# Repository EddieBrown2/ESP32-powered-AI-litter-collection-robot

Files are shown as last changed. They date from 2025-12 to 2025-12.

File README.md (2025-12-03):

# ESP32 powered AI litter collection robot
One of the biggest problems in the world today is pollution which includes litter outside and in buildings. To help solve this problem, I am going to create a small autonomous robot capable of detecting and moving litter. This robot will be capable of removing plastic environment, in order to protect them.
I have attached an entire breakdown of the project's progress if the pdf file with the name "ESP32-powered-AI-litter-collection-robot"
Youtube account with videos of progress : https://www.youtube.com/@EddieBrown-j3n

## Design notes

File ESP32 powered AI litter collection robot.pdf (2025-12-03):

ESP32 powered AI litter collection robot

Table of Contents

## Preparation

## Project overview

One of the biggest problems in the world today is pollution which includes litter outside and in buildings. To help solve this problem, I am going to create a small autonomous robot capable of detecting and moving litter. This robot will be capable of removing plastic from internal and external environments to prevent damage to the infrastructure and ecosystems of these spaces. To achieve this, I will need to follow the following specifications:
- No 3d printed components can be larger than 220 x 220 x 270 mm as these are the dimensions of the print volume for the 3d printer I will be using. I will use a 3d printer as it is quick and allows for precise, replicable manufacturing of the components in my design.
- The cost of all the components should be around £50 but no more than £100. This will ensure the robot is cheap to manufacture and can be easily replicated.
- The robot will need to include a camera for image recognition which decreases the options for microcontrollers that can be used.
- The microcontroller used also needs plenty of free GPIO pins to connect the various components necessary for the design.

## Components

For this project, I have chosen to source all the electrical components from the website Pi hut rather than directly buying from a direct electronics component’s seller such as Digi key. This reduces the number of options I have for components to use for the project but will allow me to receive the components quicker and with easier to access documentation.

Microcontroller
I will use an esp32 microcontroller to create this project, rather than a single board computer such as a raspberry pi. This will result in a lower processing power but the positive of a smaller form factor to fit into the chassis and lower power and cooling requirements. However, this also means I will only be able to power the components with 3.3V rather than 5V due to the limited power output of esp32 boards. This will limit my options in terms of components, most notably motors, but should still allow for a successful design.
The specific board I have chosen to use is the Xiao esp32 s3 sense. This is due to its small form factor, as well as having a built-in camera which leaves all the GPIO pins free to wire components to, making it ideal for my project. As well as this, it has an inbuilt module and attachment to be powered by a 3.7v lithium polymer battery and recharge the battery. This makes It easier for my project as the battery

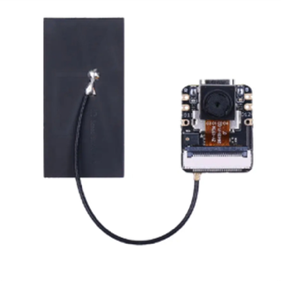
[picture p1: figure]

doesn’t have to be swapped out as often. Battery
I have chosen to use a 3.7v LIPO battery with 1200mAh of capacity. This battery will connect directly to the board, which reduces the need for extra components. It also maintains a small for factor coming in at only 5.3 x 35.5 x 64.5 mm making it ideal for a small form factor chassis.

Distance sensor
Due to the limited voltage output of the esp32 s3 chip I am using, I cannot use a standard 5v HC-SR04 ultrasonic distance sensor without the use of a voltage converter. Since using a converter can lead to unreliability in the operation of the sensor, I will instead use an ultrasonic distance sensor that uses a RCWL-1601 board instead. This means that it can be powered with voltages between 3 – 5V, making it compatible with my board.
Motors
For the powering of the wheels, I will use 2 TT Motors (which can be powered by 3 – 6V), one for each wheel. Unfortunately, as the battery only outputs 3.7V, and servo motors require an input of 5V, I will use a third TT motor to drive the claw mechanism. This means I will need to use a claw mechanism that can be continuously driven, rather than a pivot-based design.

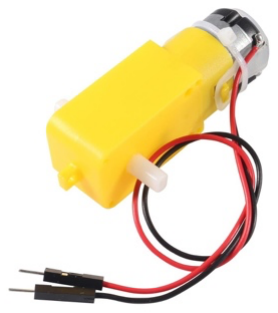
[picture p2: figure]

To drive these motors, I will use 2 HR8833 DFROBOT motor drivers one of which will allow me to power both the wheel motors and the other for just the claw driving motor. This motor driver is much smaller than most which will help limit the weight and size of my project.

Other Components
Other components I will use are:
- Proto board to allow me to easily solder the parts together without the need to design an order a custom PCB.
- Ceramic and electrolytic capacitors to
smoothen the signal between the battery and the
motor driver as well as between the motor driver and

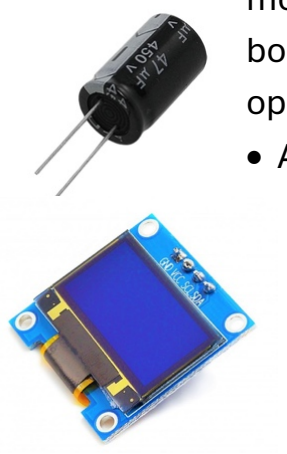
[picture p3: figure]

board. This will result in more reliable and consistent operation of the components.
- A simple OLED display to show information relating to the operation of the robot.
- Simple push buttons to allowing changing settings of various parts of the system when a WIFI – connection is not available.

## Full components List

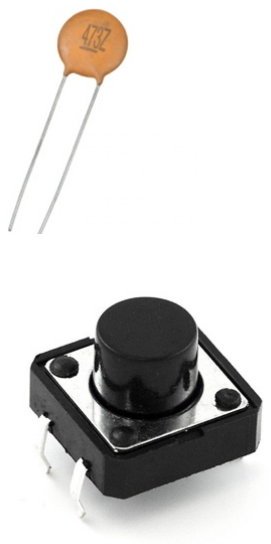
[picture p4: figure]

Component | Price
Xiao ESP32 S3 Sense | £13.50
3.7V 1200mAh LIPO battery + JST connector | £8.70
RCWL-1601 ultrasonic distance sensor | £3.90
3V TT motor * 3 | £7.80
HR8833 Motor Driver * 2 | £8.80
Proto board | £4.40
Ceramic and Electrolytic capacitors | £3.80
OLED display | £4.00
Push buttons | £2.20
Total Price | £57.10

Using these components the total price is £57.10 which makes it below the budget of £100 due to the use of the ahordable ESP32 motors as well as the use of TT motors rather than servos.

## CAD design

I have chosen to use Fusion 360 to design the 3d printed components for this project as it is a software I am familiar with and allows for the parts to be easily exported to be 3d printed.

## Claw Mechanism

I chose to first design the claw mechanism as this will heavily influence the size and shape of the final body design to house the motors, circuitry and other components.

Claw Design Ideas
I started by experimenting with various claw designs to determine the most optimal design bearing in mind the following factors:
- It must be driven by continuous rotation as that is the form of motion delivered by the TT motor I will be using.
- Have a small total size to avoid the size of the robot becoming too large. In attempt to achieve this, I will try to minimise the number of components involved in the design.

Design 1
Initially, I tried experimenting with a dual pivot driven claw, like the one showed below. However, this required a lot of components to keep the desired form factor. Furthermore, the complex geometry made it dihicult to simulate, and it would likely get jammed if 3d printed due to the large number of moving parts

Design 2
Due to the dihiculty of designs that only use rotary motion, I decided to use a slider-based design instead. To achieve this, I created a mechanism only drives one slider along the y-axis. This slider then connects to a slider for each claw along the x-axis. This results in a grabbing motion shown in the diagram below as well as the video. This design uses significantly less components while maintaining a small form factor which makes it ideal for my design. However, the rotary motion driving the claw means it is only in a tight grip for a small portion of the rotation.

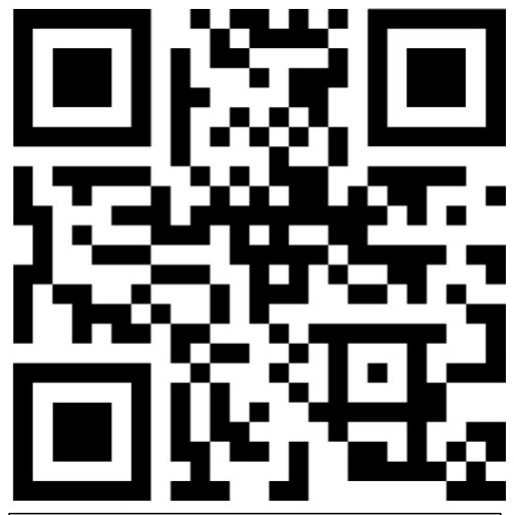
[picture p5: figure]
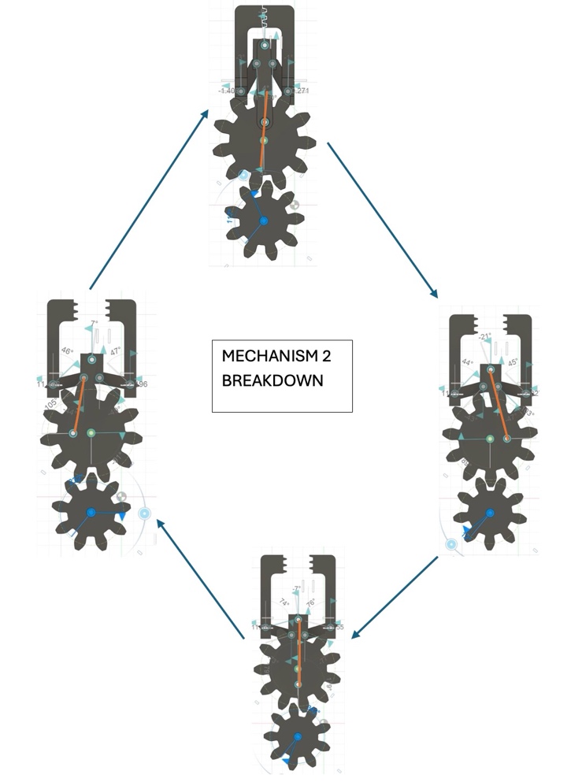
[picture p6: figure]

Video Of Mechanism

Chosen claw design
For my design I will use the second design as it is significantly more ehicient than the first.
Next, I will design the body which will be heavily influenced by the size and form factor of the chosen claw design.

## Body design

For the body design to be successful, I will need to follow the following specifications:
- It can be no larger than 220 x 220 x 270 mm as otherwise it won’t fit in the print space, I have available.
- It will need space to store the 3 TT motors which are 22.6 * 22.3 * 69.4 mm but the size of the space for each motor will have to be a millimetre or two larger to allow for tolerance when 3d printing.
- I will need to leave an open space that can hold the 50 * 70 mm perf board which the components will be soldered to.

Body design prototyping

Design 1
Initially, I tried to create a design where the motor holders were rotated along the X-axis to minimise the size of the chassis. However, this resulted in the design having a large vertical size, which would increase the cameras distance away from the claw and would also result in the design being di>icult to 3d print due to creating an excessive number of overhangs requiring lots of filament being needed to support the overhangs.

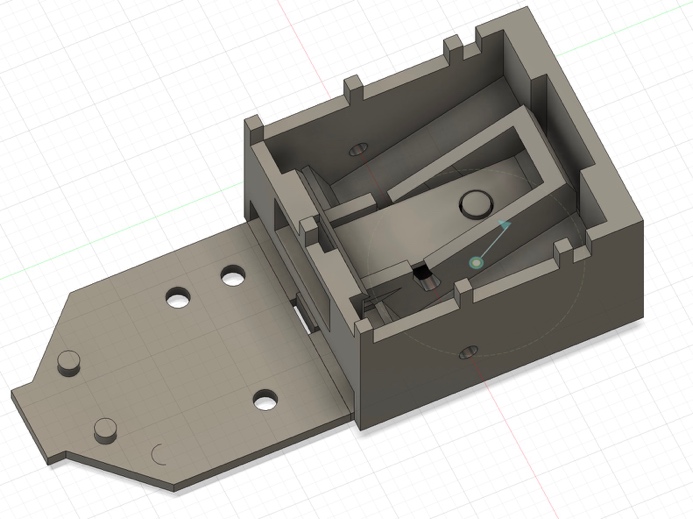
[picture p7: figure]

Design 2
I then tried a design which the motors were held flat and the camera could be held in front of the mechanism. However, this design didn’t allow space to store the circuitry.

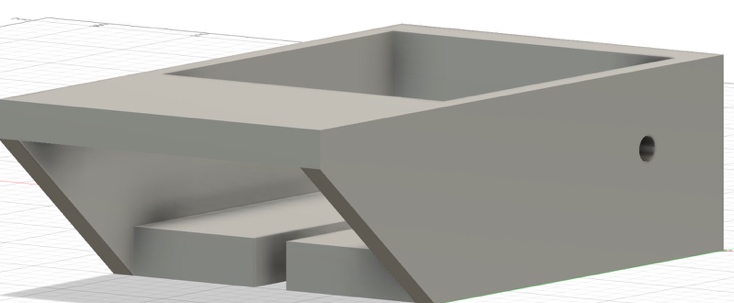
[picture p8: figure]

Design 3
For the third and final implementation of the design I split the design into the main body and a separate part to hold the circuitry and ultrasonic distance sensor. I also implemented railings into this design and adjusted the mechanism to fit.

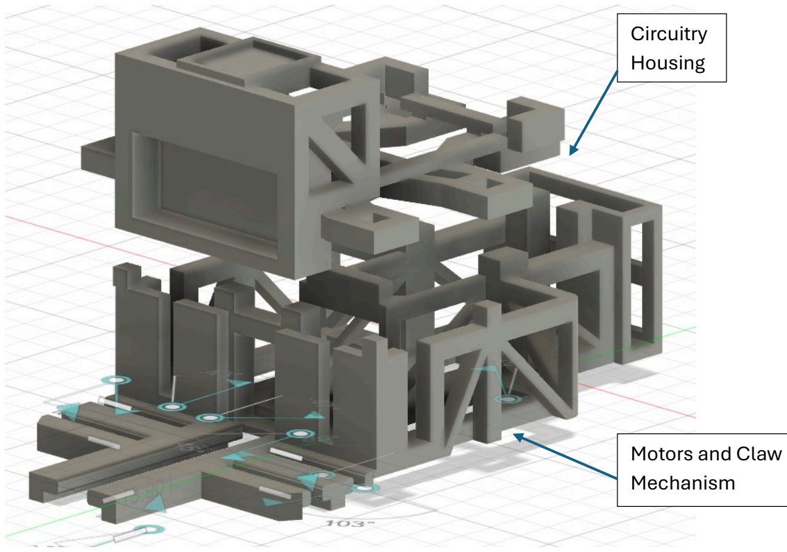
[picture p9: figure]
Circuitry Housing; Motors and Claw Mechanism
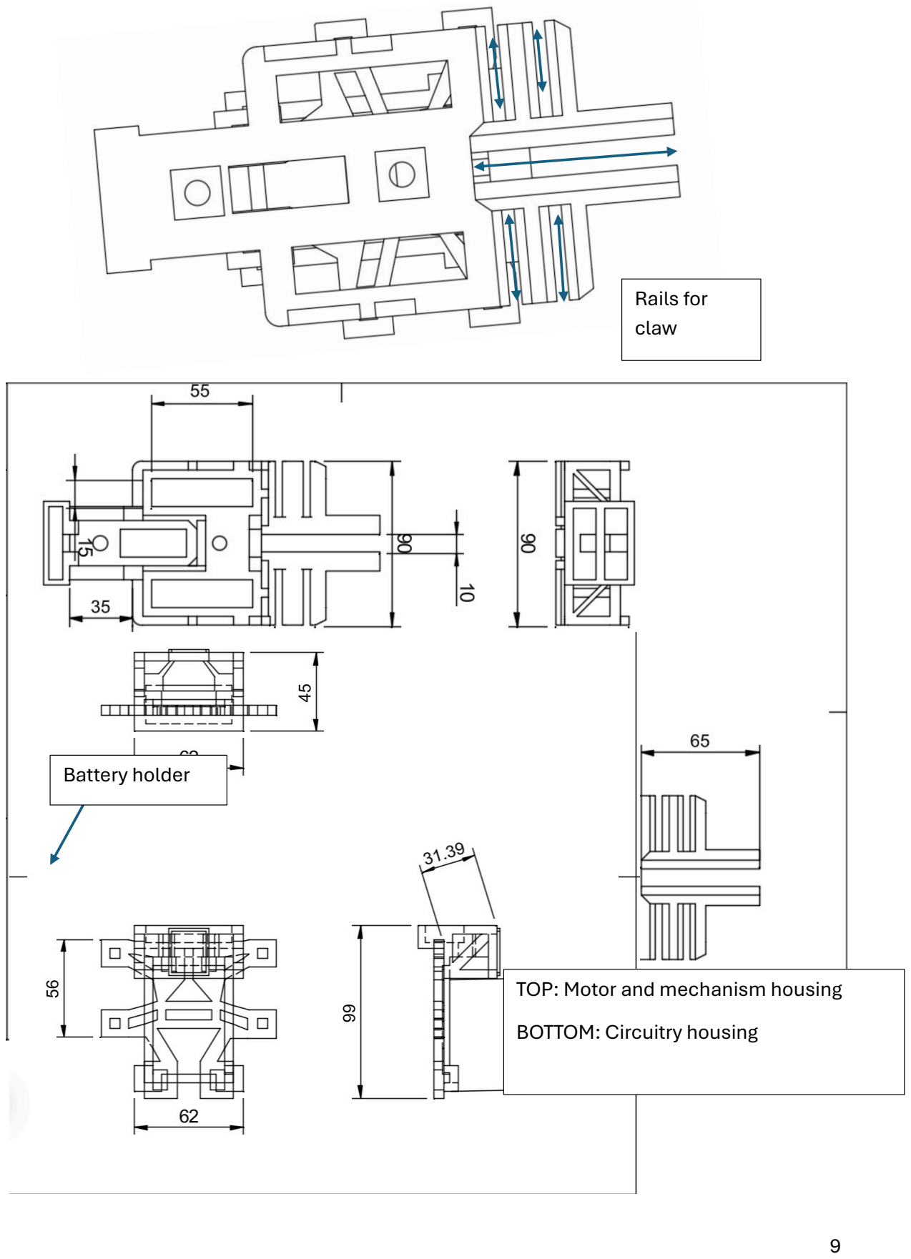
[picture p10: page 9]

Rails for
claw

TOP: Motor and mechanism housing BOTTOM: Circuitry housing

Battery holder

## Wheel Design

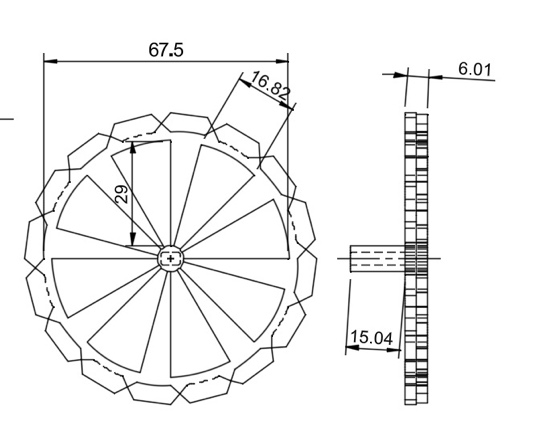
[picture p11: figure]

I chose to use a wheel with a ridged circumference in order to increase the friction and so also increase the robots grip and ability to manoeuvre across trickier terrains such as carpet or grass

## Full assembly

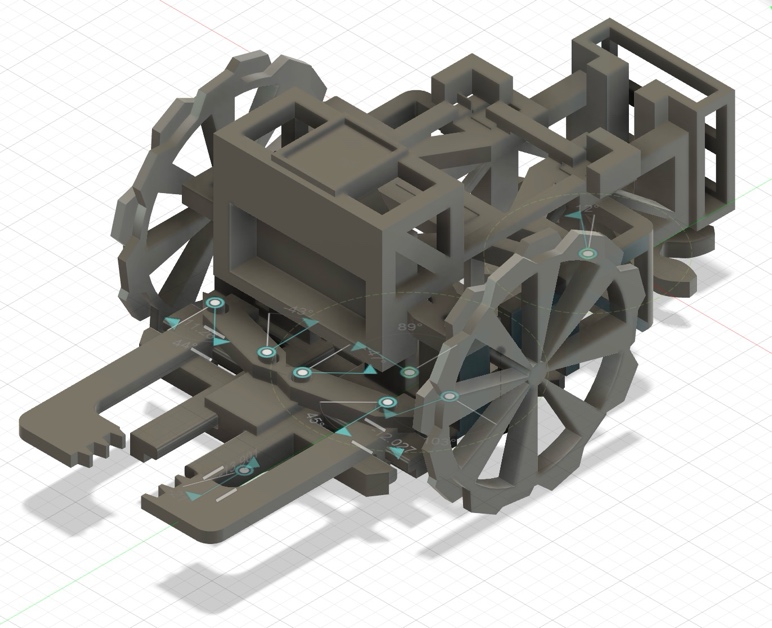
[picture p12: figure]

The picture to the left displays the entire assembly of the finished design. The total size is 110 x 70 x 200mm which means it can all be easily printed in the available print space using a minimal amount of filament

More points of contact than normal wheel = increased grip

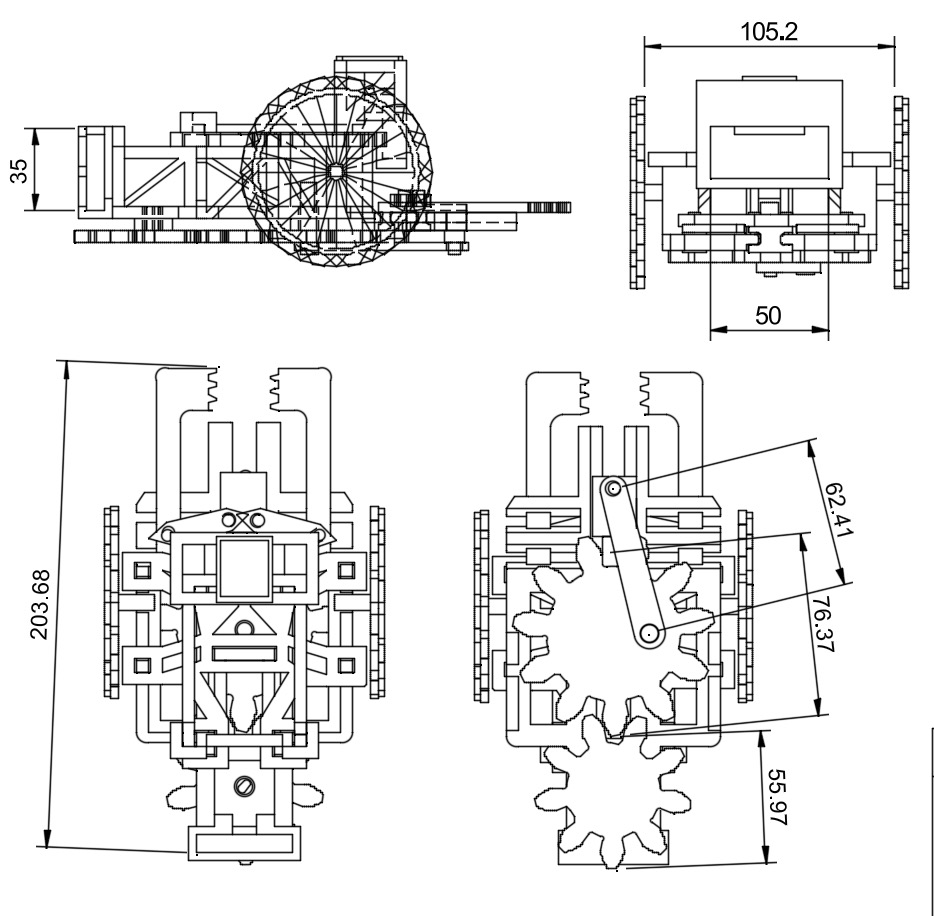
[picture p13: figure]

Full Body Drawing

## 3d printing

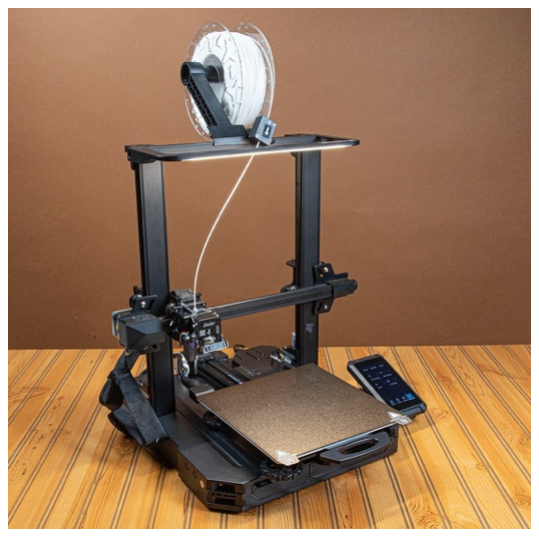
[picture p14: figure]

I chose to 3d print the design as it is an easy, quick and precise manufacturing method. The 3d printer I will use is the ender 3S1.

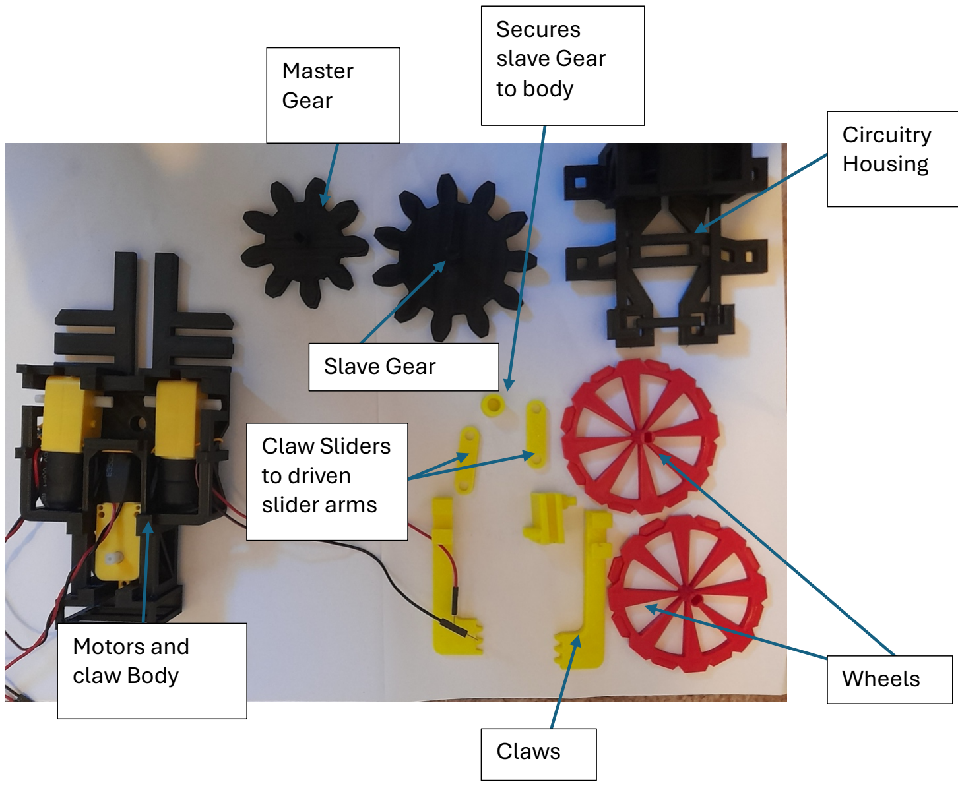
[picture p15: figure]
Slave Gear; Secures slave Gear to body; Wheels; Claws; Motors and claw Body; Master Gear; Claw Sliders to driven slider arms; Circuitry Housing

## Material

I printed my design using PLA as it is the filament type I had available at the time but if I had more time, I would have printed the design using PETG as it ohers a higher toughness which is desirable in my robot due to the mechanical parts which operate the claw mechanism.

## Tolerance Testing

I first printed a 30 x 30 mm square with holes of diherent sizes in order to find the correct size to print the holes on the master gear and wheel for attachment to the TT
motor shaft.
From this, I determined I would need to use a hole with diameter of 5.7mm and a width of 3.9mm.

## Cross Beams

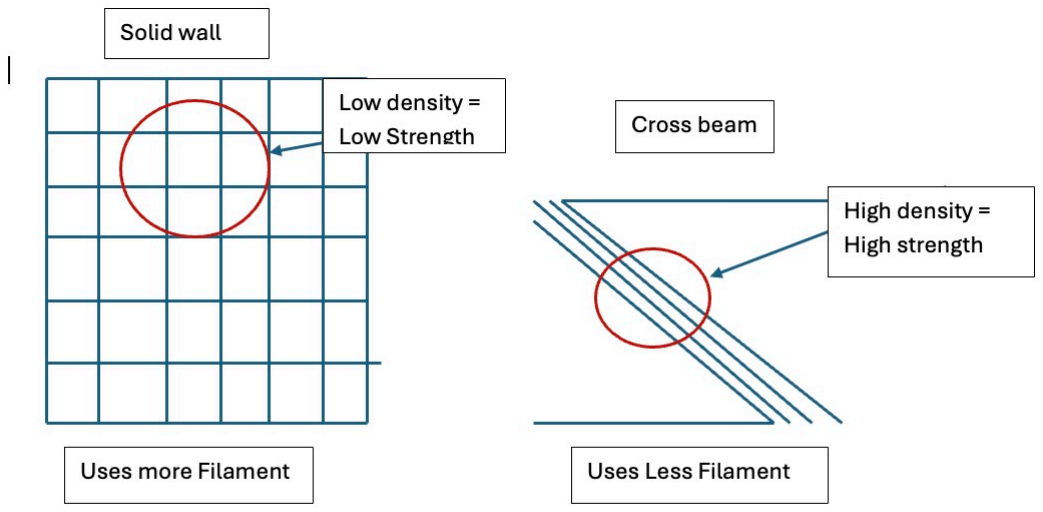
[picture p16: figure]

I used crossbeams to support the main body and parts of the Circuitry Housing. This is because Crossbeams use a lower amount of filament which reduces the amount of material and reduces the print time. It also results in a frame that is often stronger than its solid counterpart due to the high density of filament in the beam as well as the triangular structure it creates, which is capable of withstanding more force.

## Issues with design

Now that I have printed the design, I have been able to identify 3 main problems across chassis and the mechanism.
Misaligned gears

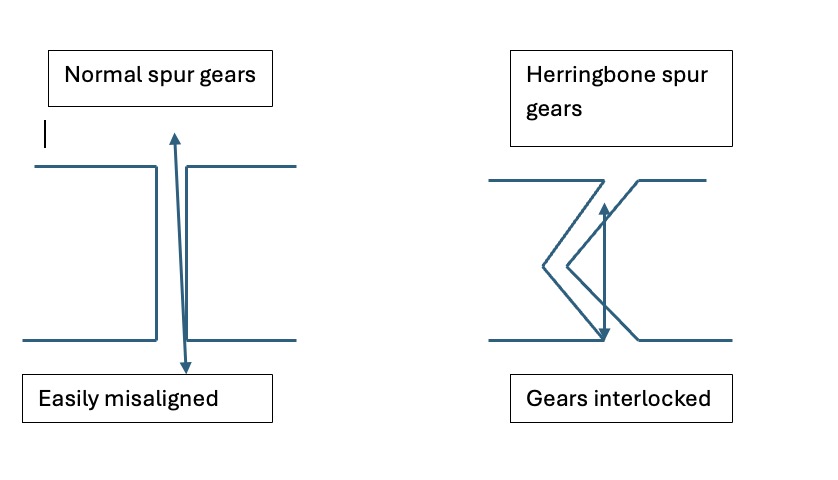
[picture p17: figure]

My current design uses normal spur gears which easily become misaligned which results in the mechanism jamming and stopping. To fix this I will reprint the gears using the herringbone design in the future. This will help the mechanism run more smoothly.

Low Grip Strength

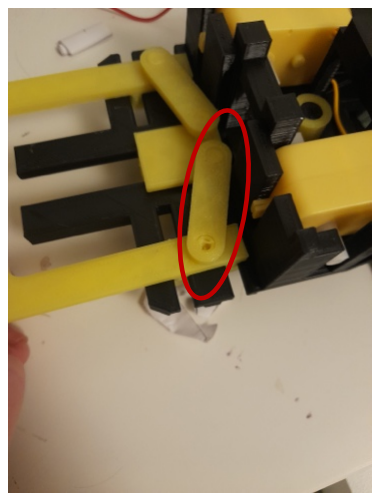
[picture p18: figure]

The design has a low grip strength because there is only one arm running between the main slider and each claw. In a future design, I will solve this by adding a second arm between the slider and each arm. This will lead to a more stable positioning of the claw and therefore a more powerful grip strength.

Scraping of mechanism

Master Gear scrapes
along the floor which can
lead to problems with the
driving of the claw

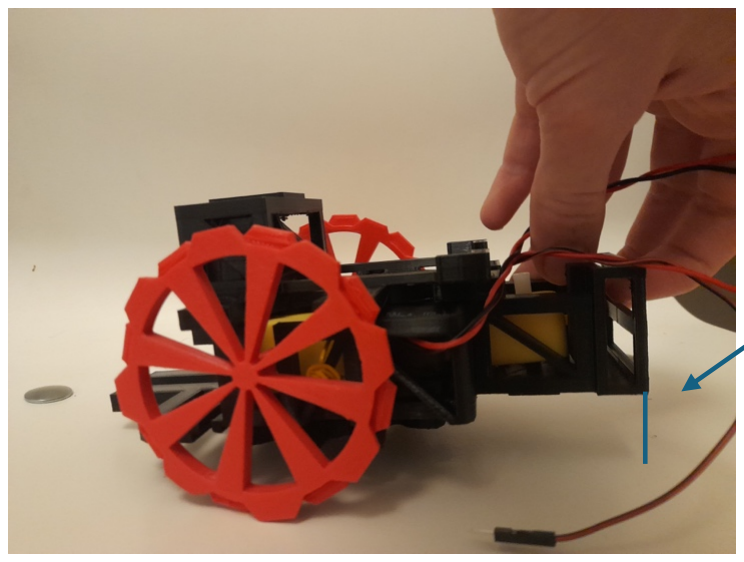
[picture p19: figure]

By lowering the rear of the chassis, it will prevent the gear from scraping along the floor.

In the future I will redesign the Chassis to prevent these issues from occurring.

## Electronics

## Schematic

Xiao Esp32 s3
sense

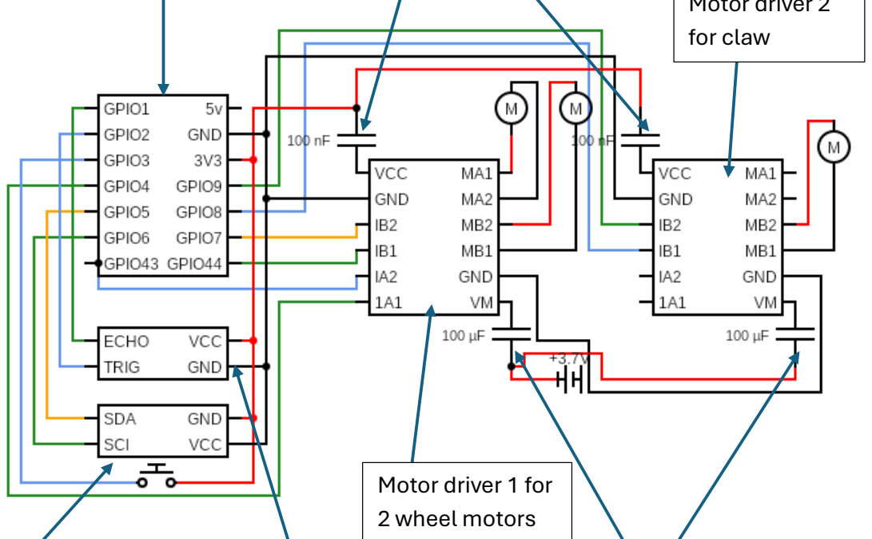
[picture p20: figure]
Motor driver 1 for 2 wheel motors; for claw

OLED display | Ultrasonic Distance sensor

Motor driver 2

Ceramic Capacitors to
smoothen signal from
board to Motor Drivers

Electrolytic Capacitors to smoothen signal from
Battery to motor drivers as well as to board

## GPIO connections

GPIO pin | Connection
GPIO1 | Distance Sensor Echo (Input)
GPIO2 | Distance Sensor Trigger (Output)
GPIO3 | Button (Input)
GPIO4 | IA1 Motor Driver 1(speed of left wheel)
GPIO5(SDA) | OLED SDA (output)
GPIO6(SCL) | OLED SCL (input)
GPIO7 | IB2 Motor Driver 1(direction of right wheel)
GPIO8 | IB1 Motor Driver 2(speed of claw)
GPIO9 | IB2 Motor Driver 2(direction of claw)
GPIO43 | IA2 Motor Driver 1(direction of left wheel)
GPIO44 | IB1 Motor Driver 1(speed of right wheel)

## Soldering

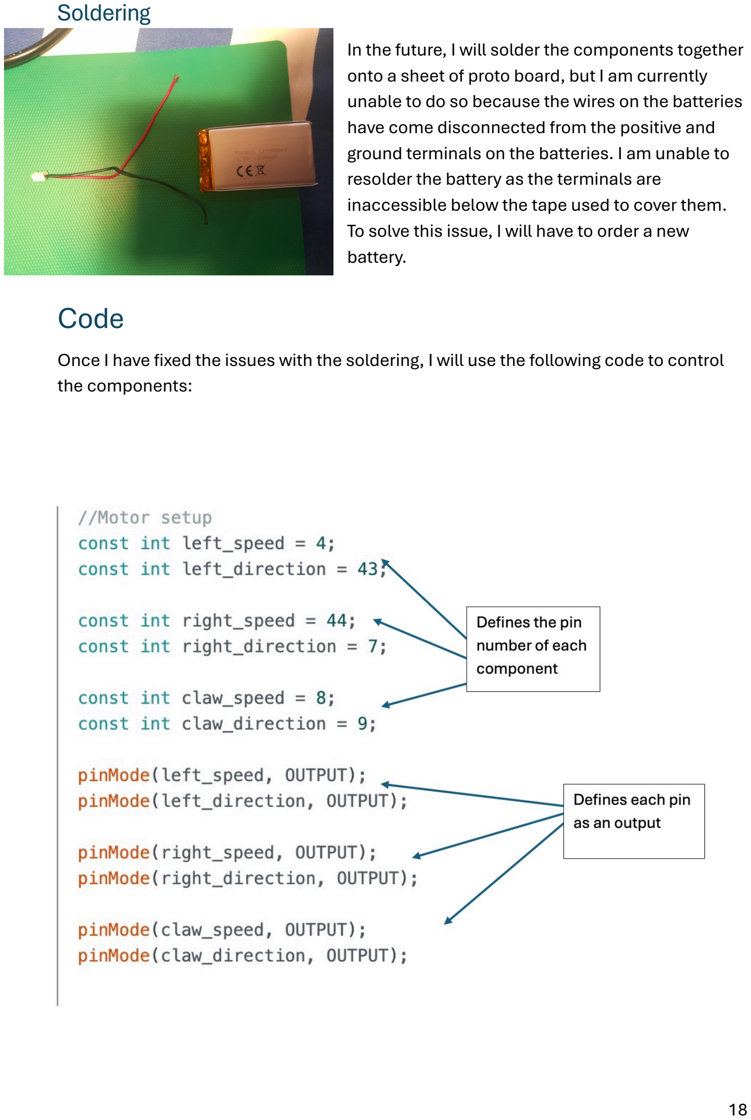
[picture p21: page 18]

In the future, I will solder the components together onto a sheet of proto board, but I am currently unable to do so because the wires on the batteries have come disconnected from the positive and ground terminals on the batteries. I am unable to resolder the battery as the terminals are inaccessible below the tape used to cover them. To solve this issue, I will have to order a new battery.

## Code

Once I have fixed the issues with the soldering, I will use the following code to control the components:

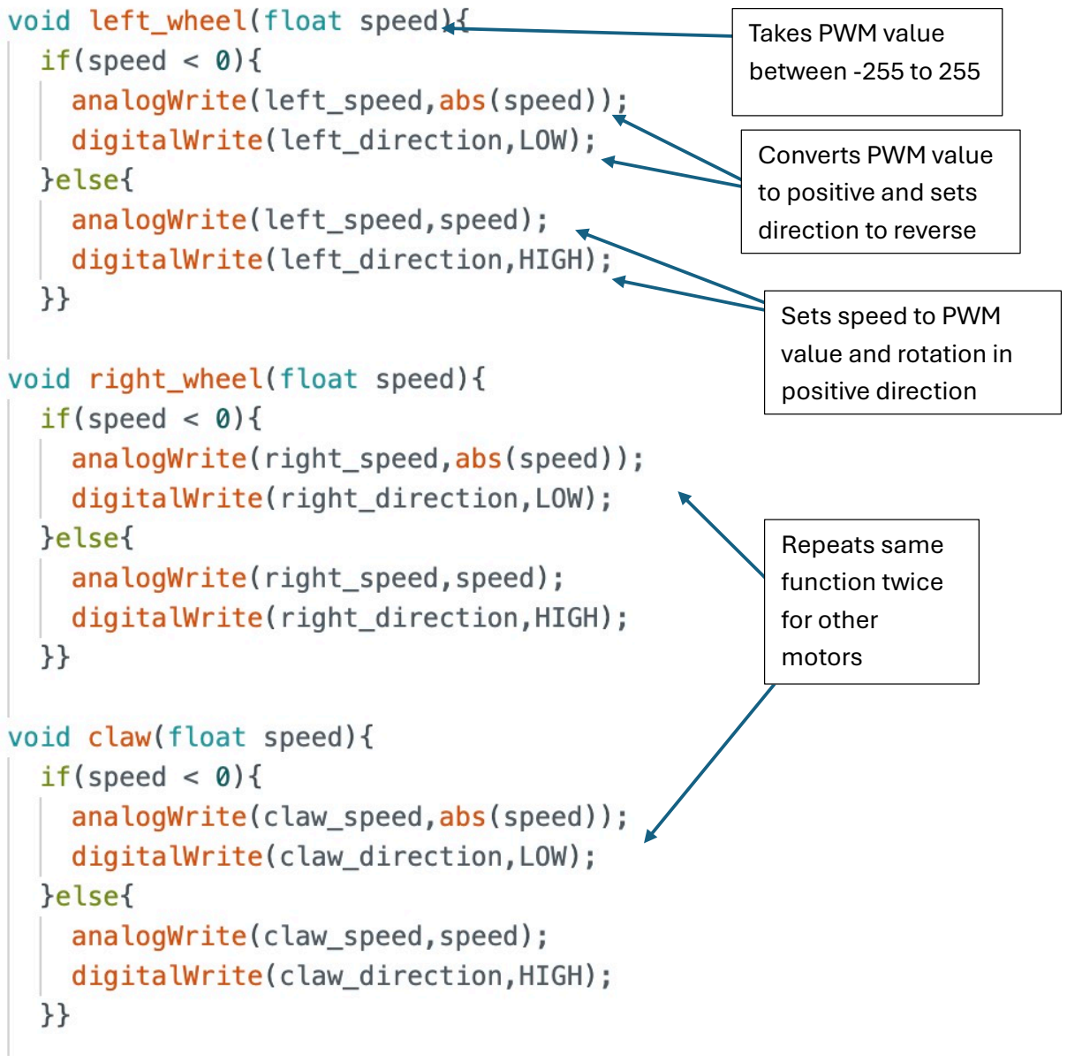
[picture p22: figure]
Takes PWM value between -255 to 255; Repeats same function twice for other motors; Converts PWM value to positive and sets direction to reverse; Sets speed to PWM value and rotation in positive direction
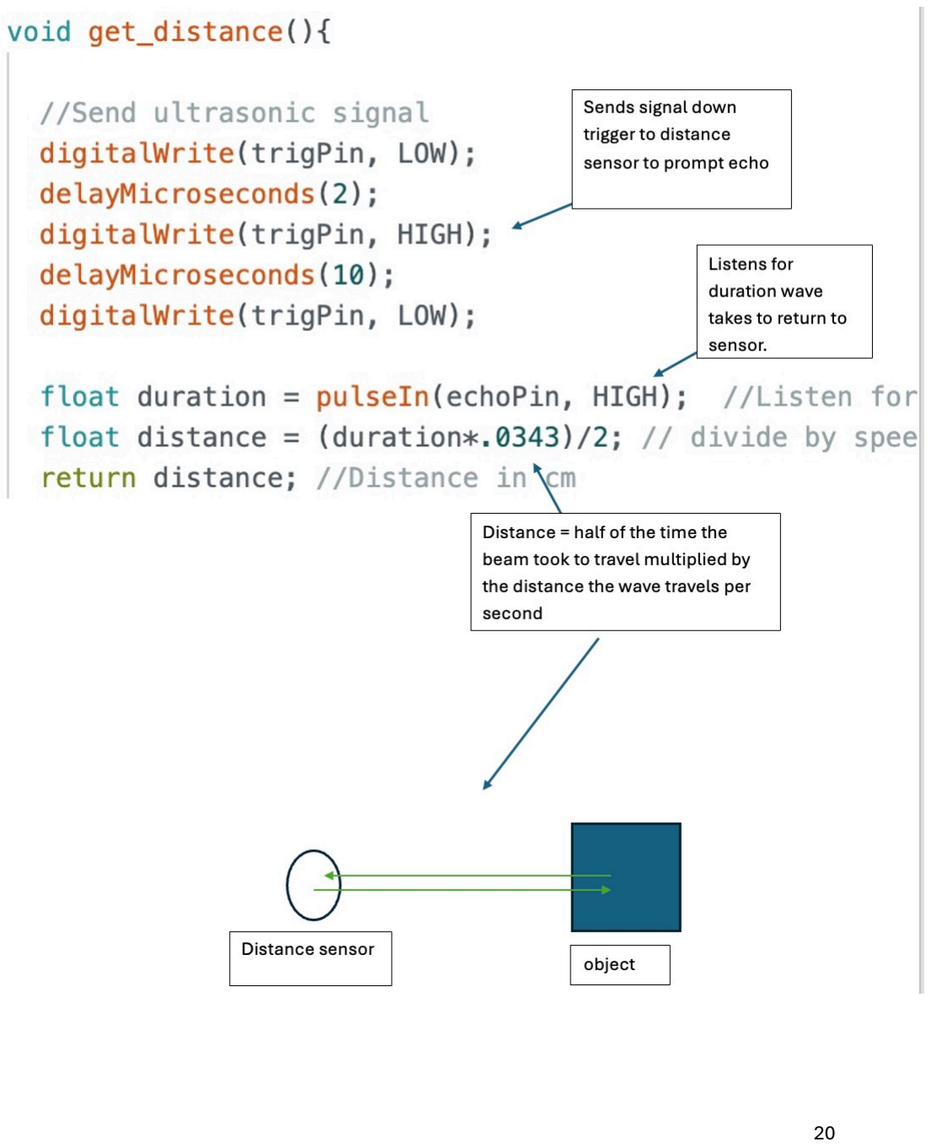
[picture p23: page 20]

## Litter recognition

I will use an edge impulse model trained on the TACO dataset which features a wide array of labelled images of litter making it ideal for the training of my model.

## Slam algorithm

In order to allow the robot to navigate I will use a SLAM (or Simultaneous Localisation Algorithm which operate by navigating to unexplored frontiers in order to document and navigate its environment.

## Litter positioning

As most of the pieces of litter will be too irregular in shape to be detected by the distance sensor, I will instead use a mathematical approach to calculate the position of the plastic based on the angles, which it can be seen from at diherent positions

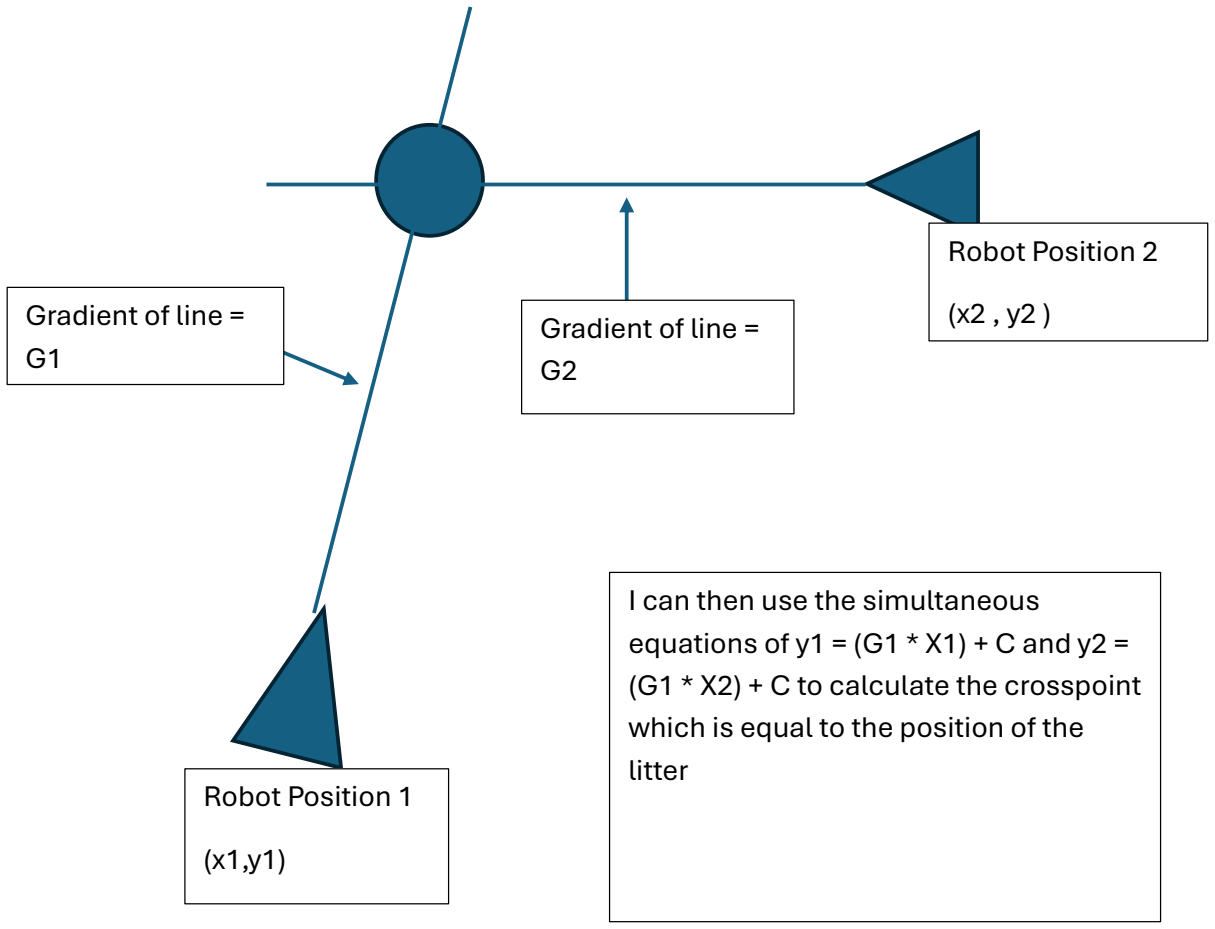
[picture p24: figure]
Robot Position 1; Robot Position 2; Gradient of line =; Gradient of line = G2; I can then use the simultaneous; which is equal to the position of the litter

equations of y1 = (G1 * X1) + C and y2 = (G1 * X2) + C to calculate the crosspoint

## Next Steps

Next, I will solder the parts together and then implement the code to control the parts. I can them implement the code to identify and locate the litter as well as navigate the environment. Then, I will need to make the robot capable of using the claw to connect and move litter.

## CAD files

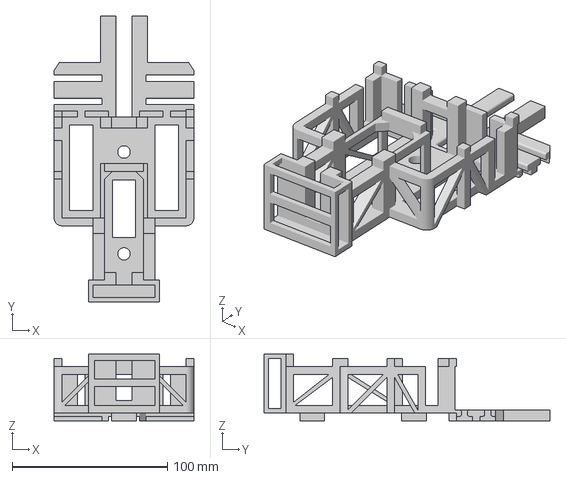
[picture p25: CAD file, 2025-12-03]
Generation 1 parts/Main Body.3mf
90.0 x 184.0 x 43.0 mm

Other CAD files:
Generation 1 parts/Claw to Gear arm.f3d
Generation 1 parts/Left Claw.f3d
Generation 1 parts/Master Gear.f3d
Generation 1 parts/Master Slider.f3d
Generation 1 parts/Proto-Board housing.f3d
Generation 1 parts/Right Claw.f3d
Generation 1 parts/Slave gear.f3d
Generation 1 parts/Slider to Claw arm.f3d
Generation 1 parts/Wheel.f3d
